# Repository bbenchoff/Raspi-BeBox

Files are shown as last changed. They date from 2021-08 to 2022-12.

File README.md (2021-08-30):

# Raspi-BeBox
## A Raspberry Pi case that looks like a wee BeBox

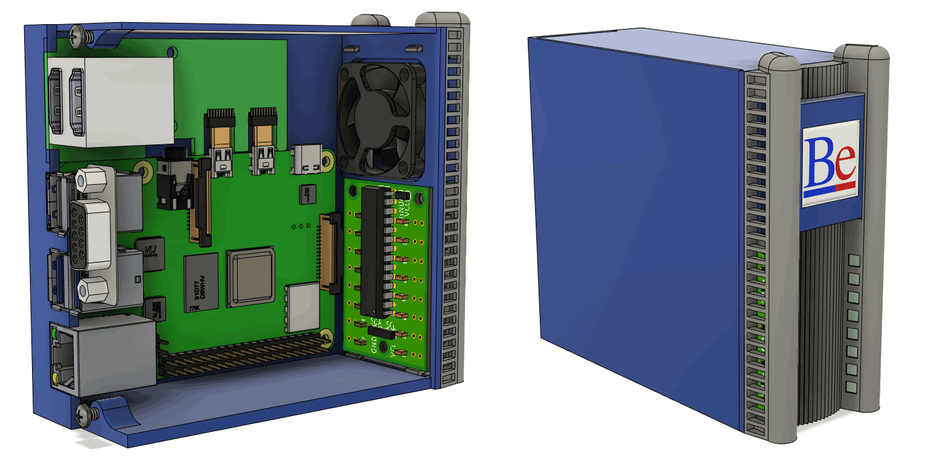
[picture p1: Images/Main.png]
Renders

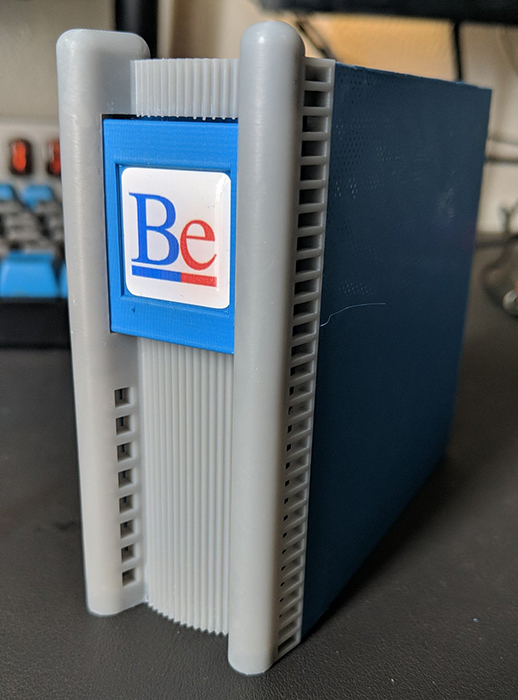
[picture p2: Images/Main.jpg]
Side view


There are several components of the BeBox, including 3D printed (filament), 3D printed (SLA), circuit boards, and random stuff picked up from Amazon:

### BlinkenPanel
The BlinkenPanel displays CPU usage on 16 LEDs shinging through the front. The [project is shared on OSHPark](https://oshpark.com/shared_projects/XPZorljf). Other components needed for this are:

* Green Square LEDs - Part Number SSL-LX3353GD
* I2C GPIO expander - MCP23017-E/SP
* Resistors of various sort - 0805
* DC Fan 5V - any 30mm fan for a Raspberry Pi

### Front panel
The heart of the BeBox - a front panel with Blinkenlights. This [is available on Shapeways](https://www.shapeways.com/product/FETJ2WU6V/raspi-bebox-face?optionId=224175918) or in the 3D files folder of this repository. Print with gray resin.

### Case Badge
...Comes from [Case Badges](https://www.case-badges.com), have them make a 0.75" square domed badge of the images in the /Graphics folder of this repository

### Interior. 
The case is designed for a Raspberry Pi 4, along with a dual microHDMI adapter board:

* [Buy these adapter boards](https://www.amazon.com/gp/product/B08V5MXLS6)
* [and this USB-C right angle adapter](https://www.amazon.com/gp/product/B086W2LTGY)

Screw bosses are sized for No. 4 screws.

## Assembly

Insert the LEDs in one side of the front panel. The anode (+) goes toward the middle. Bend the cathode (-) out. Fit the PCB with only the anodes of one side installed. Glue is recommended to hold the LEDs in place.

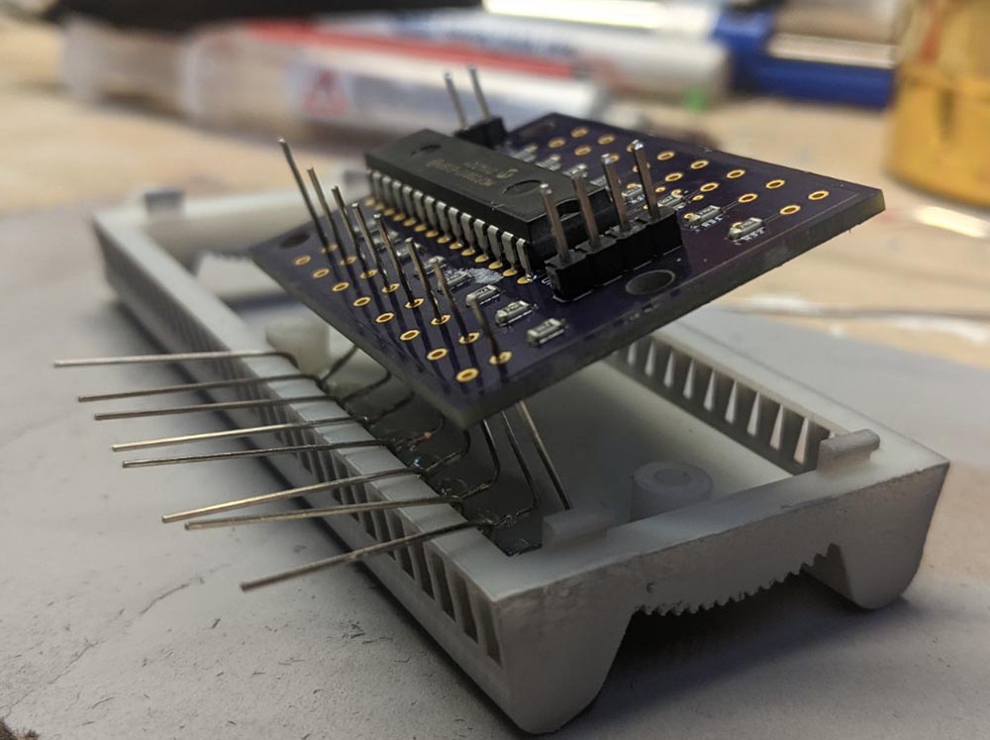
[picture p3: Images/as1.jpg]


Install the other side of the LEDs, anode only.

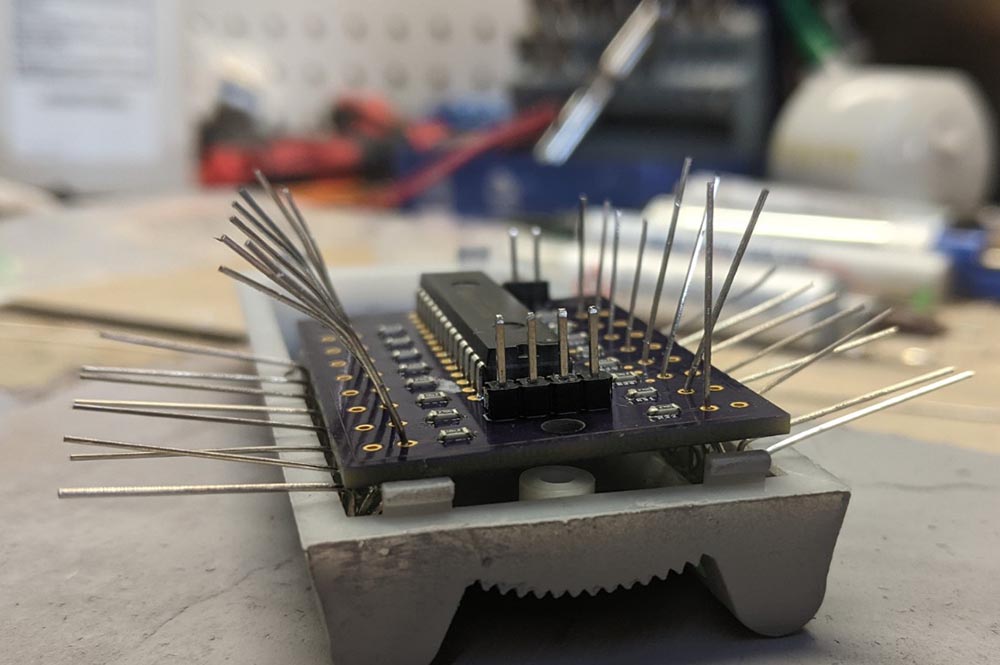
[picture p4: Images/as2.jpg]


Mount the PCB to the front panel with screws. Solder the anodes of the LEDs. Bend the cathode legs around the PCB to the other LED solder pads.
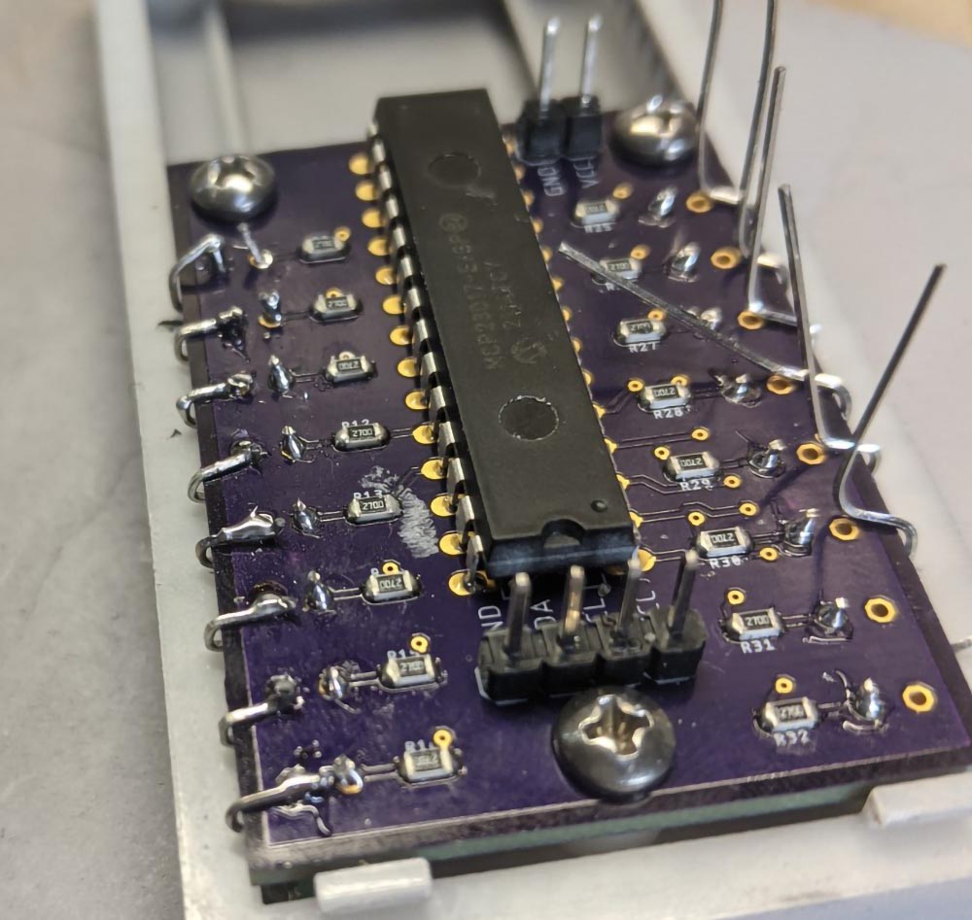
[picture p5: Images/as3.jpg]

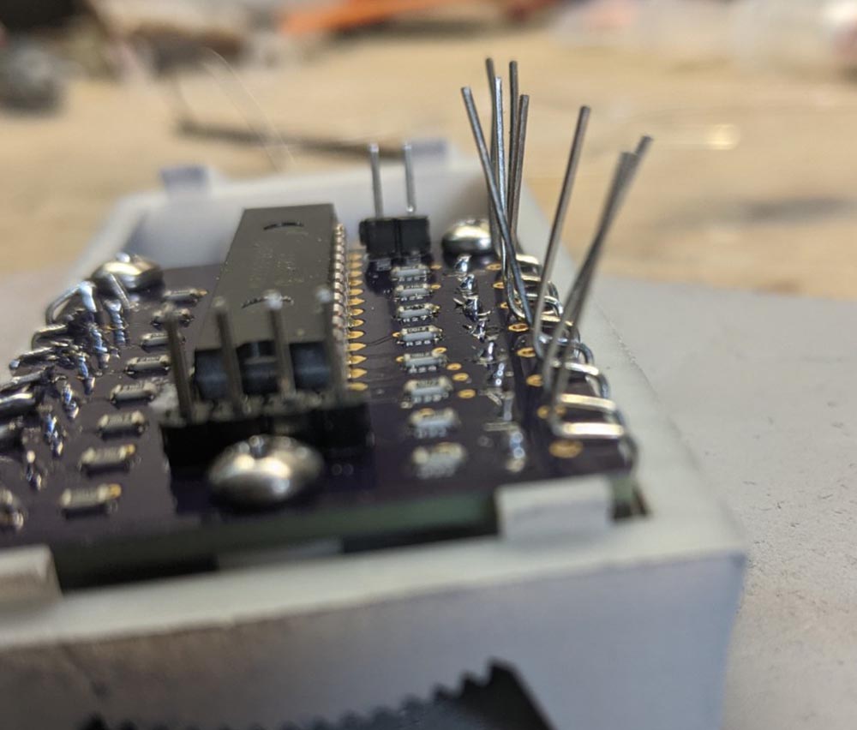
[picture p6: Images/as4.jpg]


That's it! That's the easiest way to assemble this thing. Now write some python for the blinkenlights.

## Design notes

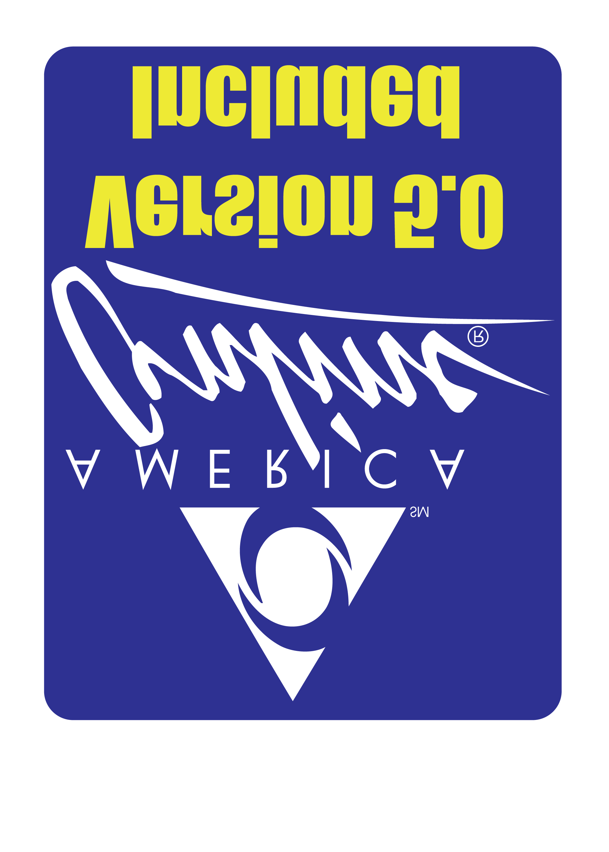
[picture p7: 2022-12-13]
OtherGraphics/AOL_flipped.png

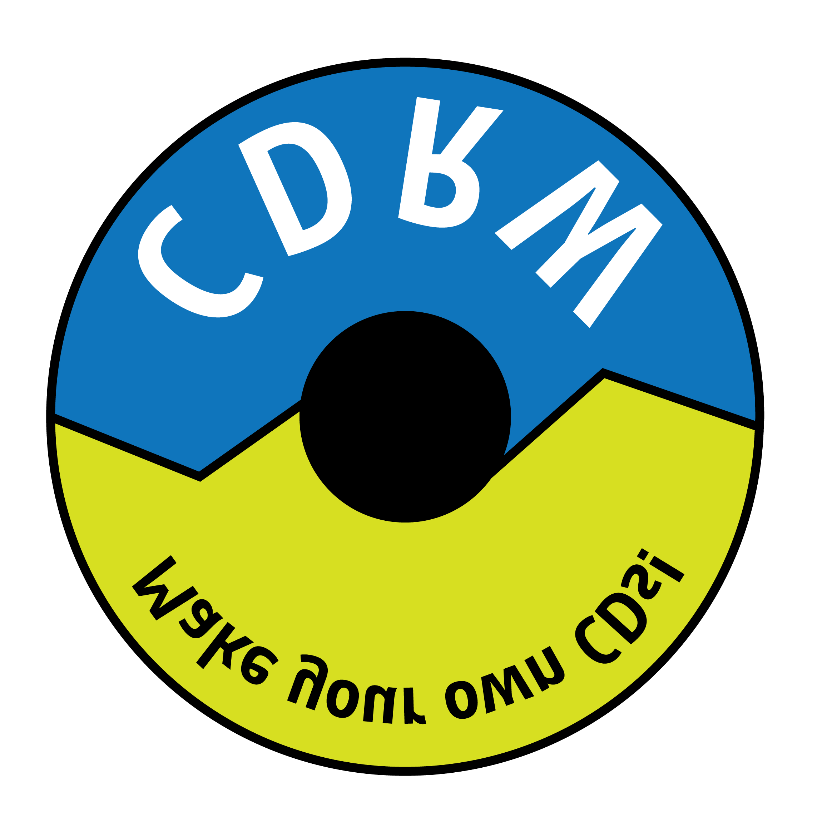
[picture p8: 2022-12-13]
OtherGraphics/CDs_flipped.png

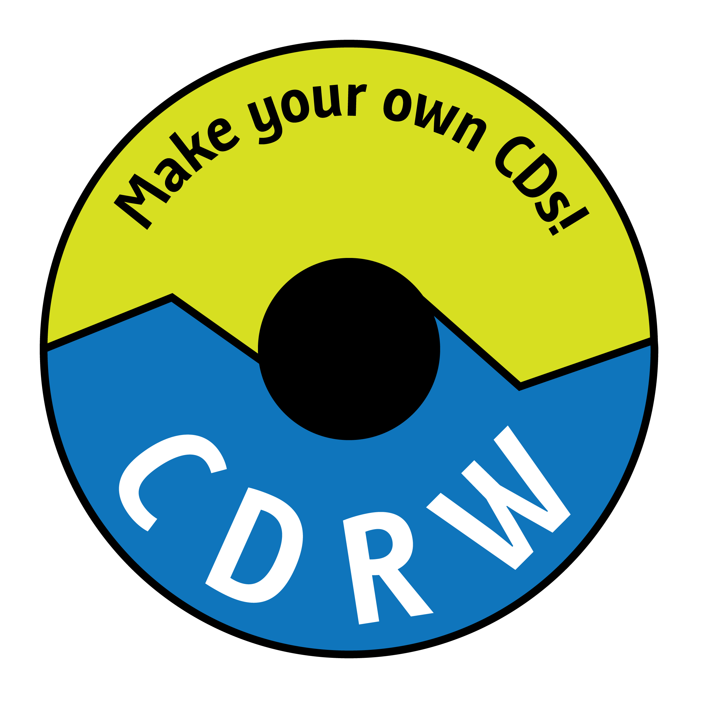
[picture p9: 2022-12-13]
OtherGraphics/CDs.png

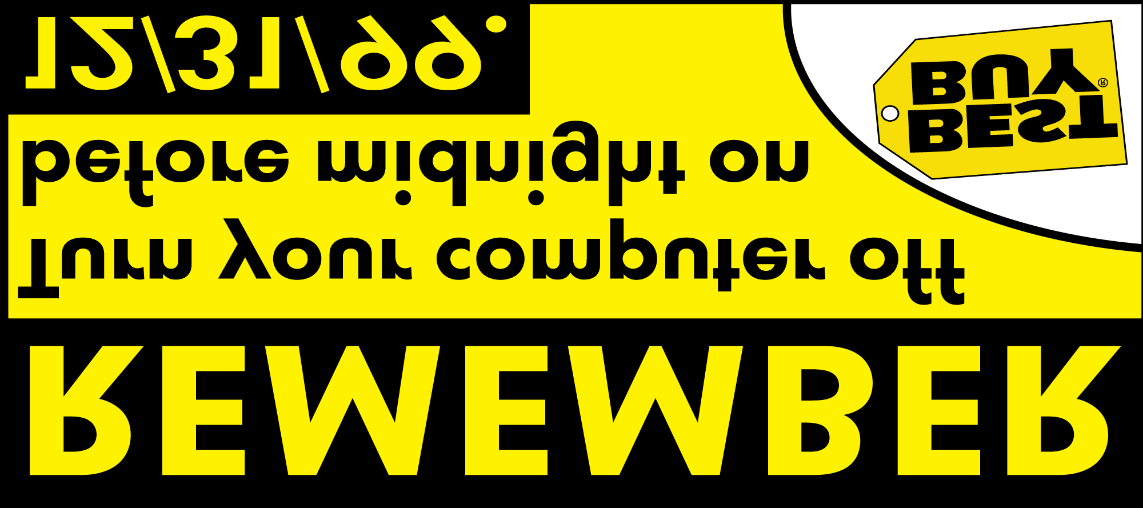
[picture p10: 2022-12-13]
OtherGraphics/y2k_flipped.png

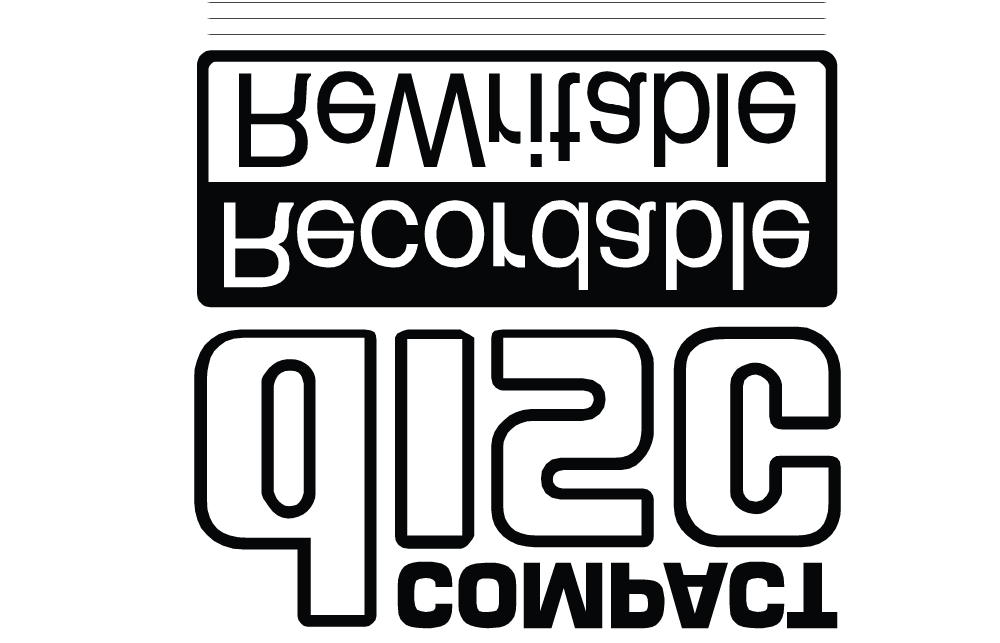
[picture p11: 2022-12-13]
OtherGraphics/CDrw_flipped.png

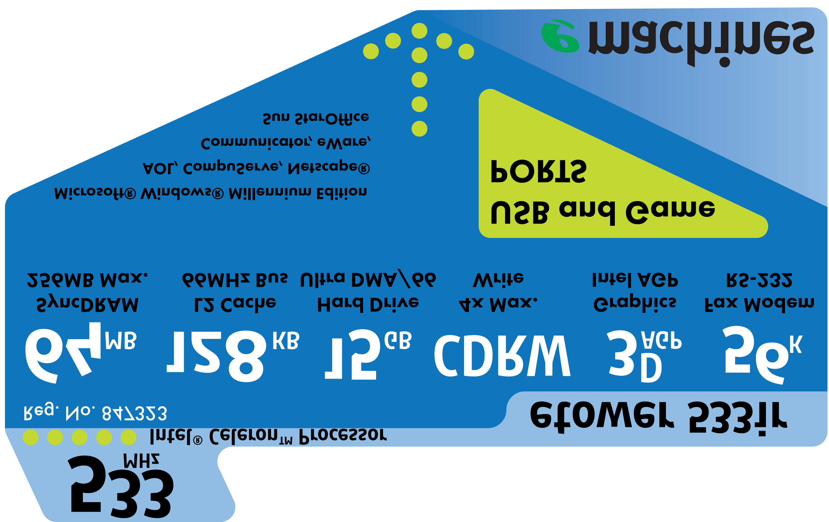
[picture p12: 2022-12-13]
OtherGraphics/BigSticker_flipped.png

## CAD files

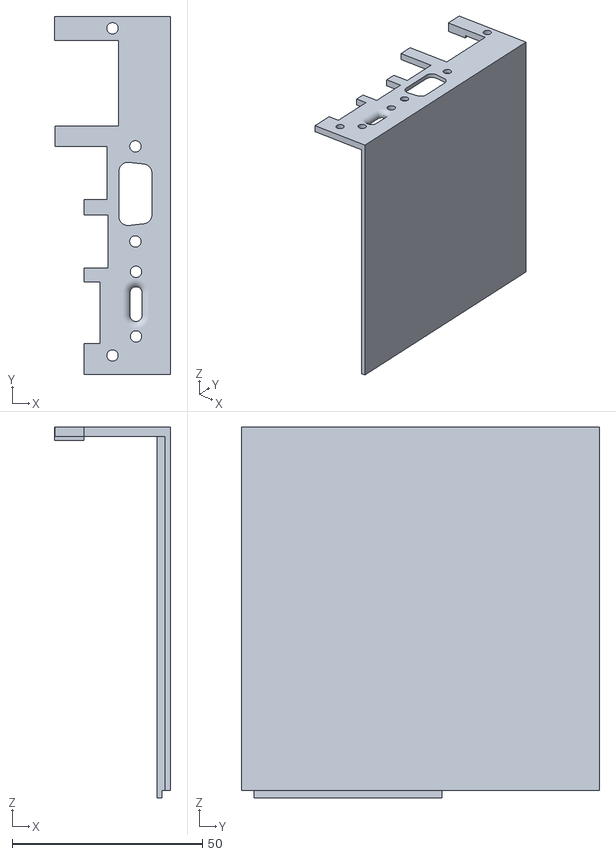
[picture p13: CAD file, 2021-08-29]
3D Prints/Left.stl
30.5 x 94.1 x 97.5

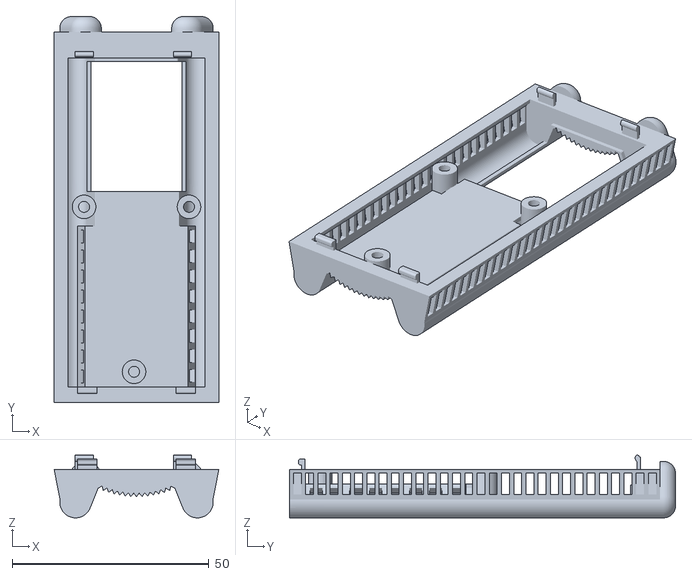
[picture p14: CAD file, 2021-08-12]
3D Prints/Face.stl
41.9 x 98.1 x 15.9

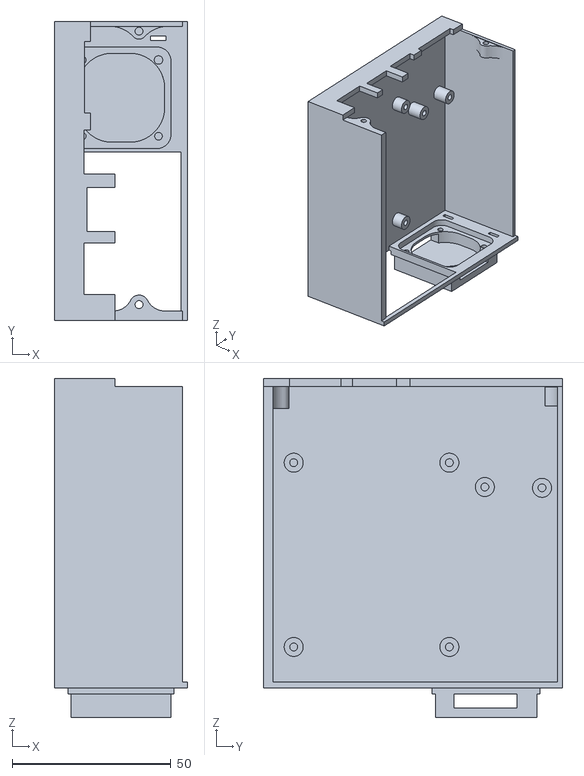
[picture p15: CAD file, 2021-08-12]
3D Prints/Right.stl
41.9 x 94.1 x 106.7

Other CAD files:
3D Prints/Left-Without-Serial.stl

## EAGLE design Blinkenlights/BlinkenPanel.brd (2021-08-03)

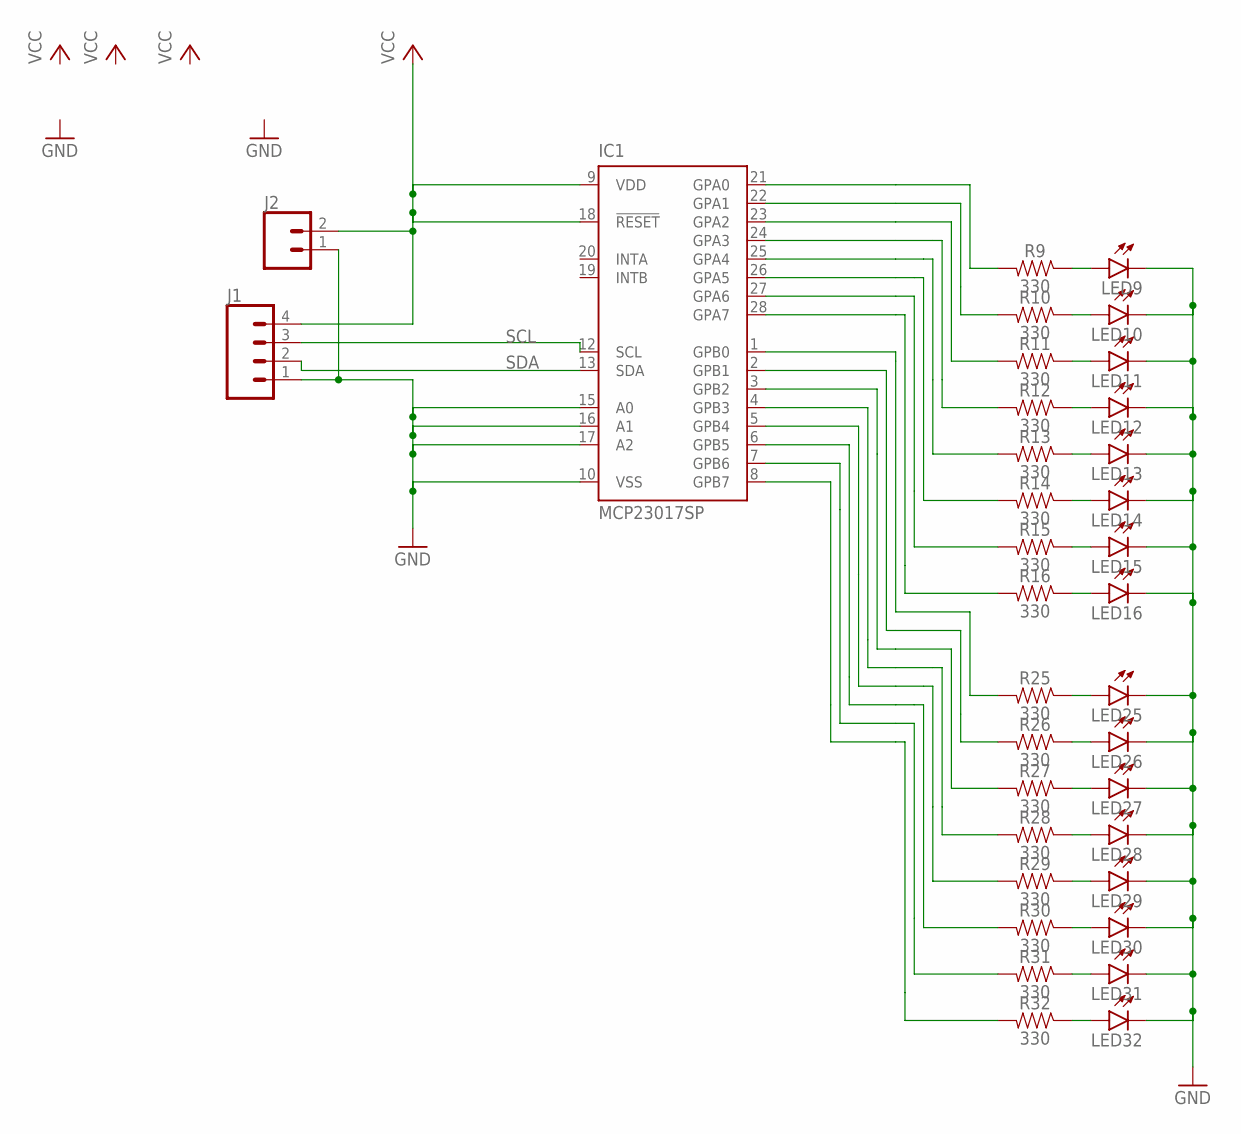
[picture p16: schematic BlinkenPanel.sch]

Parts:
IC1: MCP23017SP; DIL28-3
J1: CONN_04LOCK; 1X04_LOCK
J2: CONN_02; 1X02
LED9, LED10, LED11, LED12, LED13, LED14, LED15, LED16, LED25, LED26, LED27, LED28, LED29, LED30, LED31, LED32: LED3MM
R9, R10, R11, R12, R13, R14, R15, R16, R25, R26, R27, R28, R29, R30, R31, R32: 330; 0603

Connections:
GND: IC1.10 (VSS), IC1.15 (A0), IC1.16 (A1), IC1.17 (A2), J1.1, J2.1, LED9.K (C), LED10.K (C), LED11.K (C), LED12.K (C), LED13.K (C), LED14.K (C), LED15.K (C), LED16.K (C), LED25.K (C), LED26.K (C), LED27.K (C), LED28.K (C), LED29.K (C), LED30.K (C), LED31.K (C), LED32.K (C)
unnamed: LED9.A, R9.1
unnamed: LED10.A, R10.1
unnamed: LED11.A, R11.1
unnamed: LED12.A, R12.1
unnamed: LED13.A, R13.1
unnamed: LED14.A, R14.1
unnamed: LED15.A, R15.1
unnamed: LED16.A, R16.1
unnamed: IC1.21 (GPA0), R9.2
unnamed: IC1.22 (GPA1), R10.2
unnamed: IC1.23 (GPA2), R11.2
unnamed: IC1.24 (GPA3), R12.2
unnamed: IC1.25 (GPA4), R13.2
unnamed: IC1.26 (GPA5), R14.2
unnamed: IC1.27 (GPA6), R15.2
unnamed: IC1.28 (GPA7), R16.2
unnamed: LED25.A, R25.1
unnamed: LED26.A, R26.1
unnamed: LED27.A, R27.1
unnamed: LED28.A, R28.1
unnamed: LED29.A, R29.1
unnamed: LED30.A, R30.1
unnamed: LED31.A, R31.1
unnamed: LED32.A, R32.1
unnamed: IC1.1 (GPB0), R25.2
unnamed: IC1.2 (GPB1), R26.2
unnamed: IC1.3 (GPB2), R27.2
unnamed: IC1.4 (GPB3), R28.2
unnamed: IC1.5 (GPB4), R29.2
unnamed: IC1.6 (GPB5), R30.2
unnamed: IC1.7 (GPB6), R31.2
unnamed: IC1.8 (GPB7), R32.2
SCL: IC1.12 (SCL), J1.3
SDA: IC1.13 (SDA), J1.2
VCC: IC1.9 (VDD), IC1.18 (!RESET), J1.4, J2.2

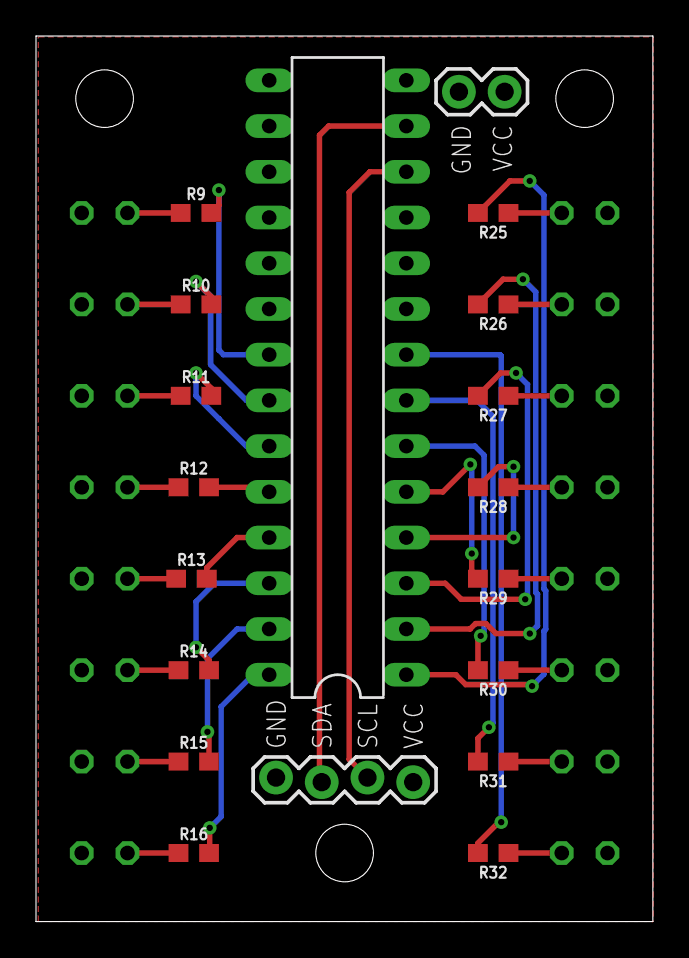
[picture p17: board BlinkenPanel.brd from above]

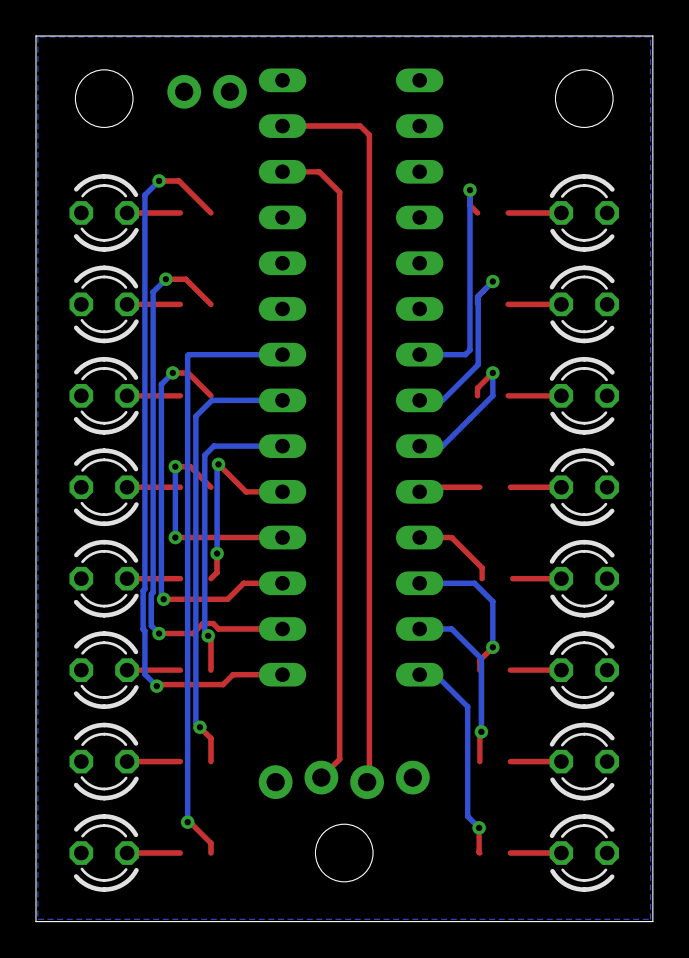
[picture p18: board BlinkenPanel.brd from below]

Board: 2 copper layers, 34.3 x 49.2 mm, 35 parts (16 on the bottom side), 36 nets.

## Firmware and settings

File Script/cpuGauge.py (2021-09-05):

import smbus
import time
import psutil

bus = smbus.SMBus(1)

DEVICE = 0x20
IODIRA = 0x00
IODIRB = 0x01
RIGHTLED = 0x15
LEFTLED = 0x14 
GPIOA = 0x12

binarylist = [128,128,192,224,240,248,252,254,255,255]

#define all GPB pins as output
bus.write_byte_data(DEVICE,IODIRB,0x00)

#define all GPA pins as output
bus.write_byte_data(DEVICE,IODIRA,0x00)

def getCPU():
    cpuNum = int(psutil.cpu_percent()/10)
    bus.write_byte_data(DEVICE,LEFTLED,binarylist[cpuNum])
    bus.write_byte_data(DEVICE,RIGHTLED,binarylist[cpuNum])
    print(cpuNum)
    
while True:
    
    time.sleep(0.05)
    getCPU()

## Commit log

2021-07-29 make a blinkenpanel
    [BlinkenPanel.brd, BlinkenPanel.sch]
2021-08-03 added prints, fixed blinkenpanel
    [BlinkenPanel.brd, BlinkenPanel.sch, Face.stl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]
2021-08-12 updated 3D prints
    [Face.stl, Left.stl, Right.stl]
2021-08-12 added without serial
    [Left-Without-Serial.stl]
2021-08-29 Added assembly instructions
    [Left.stl]
2021-08-29 README.md: fix link to case-badges.com

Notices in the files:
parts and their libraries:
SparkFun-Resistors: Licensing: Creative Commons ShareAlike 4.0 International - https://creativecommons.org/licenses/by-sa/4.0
